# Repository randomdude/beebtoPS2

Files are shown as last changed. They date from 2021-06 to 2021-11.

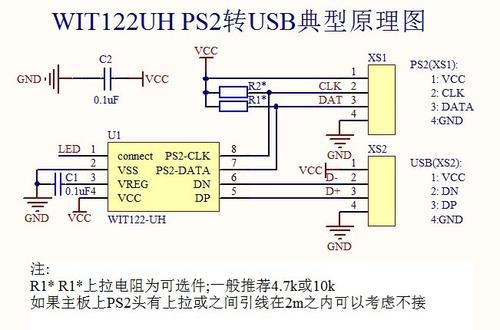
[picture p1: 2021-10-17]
dox/wit122uh.jpg

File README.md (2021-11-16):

Here's a project to enable you to use a modern (ish) PS/2 keyboard on your BBC Micro.

It is built around a Xilinx XC95144XL CPLD. Originally it was in a XC9572, which I love because they are 5v tolerant and also available in PLCC package. However, the design outgrew that chip, and so the TQFP XC95144XL is now required.

The board itself is pretty simple. There's a comparator and a couple octal buffers to sequence power, since otherwise the IO lines may go higher than vcc during power-up, by enough that the CPLD can be damaged. Then there's just the PS/2 socket for your keyboard, 8 debug LEDs, and some DIP switches (which map to the BBC micro's configuration bits). 

Please let me know if you build one, or find this interesting!

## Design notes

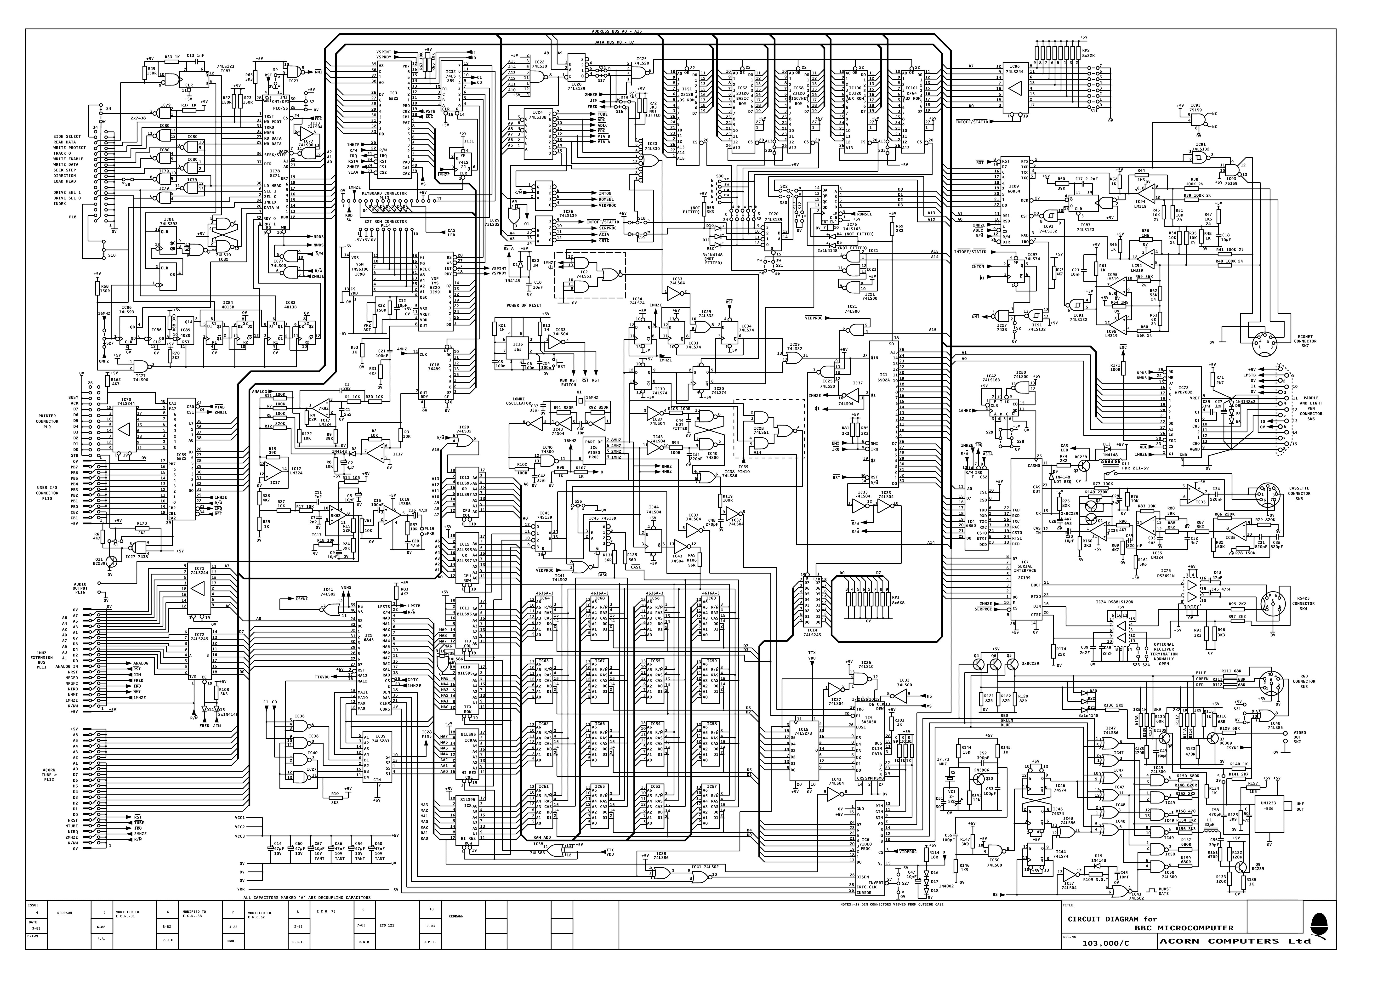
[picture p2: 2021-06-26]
dox/BBC B schematics clean.png

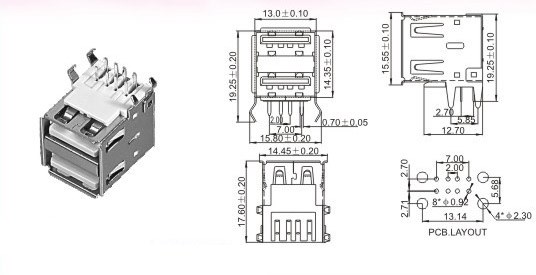
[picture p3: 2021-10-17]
dox/usbsocket.jpg

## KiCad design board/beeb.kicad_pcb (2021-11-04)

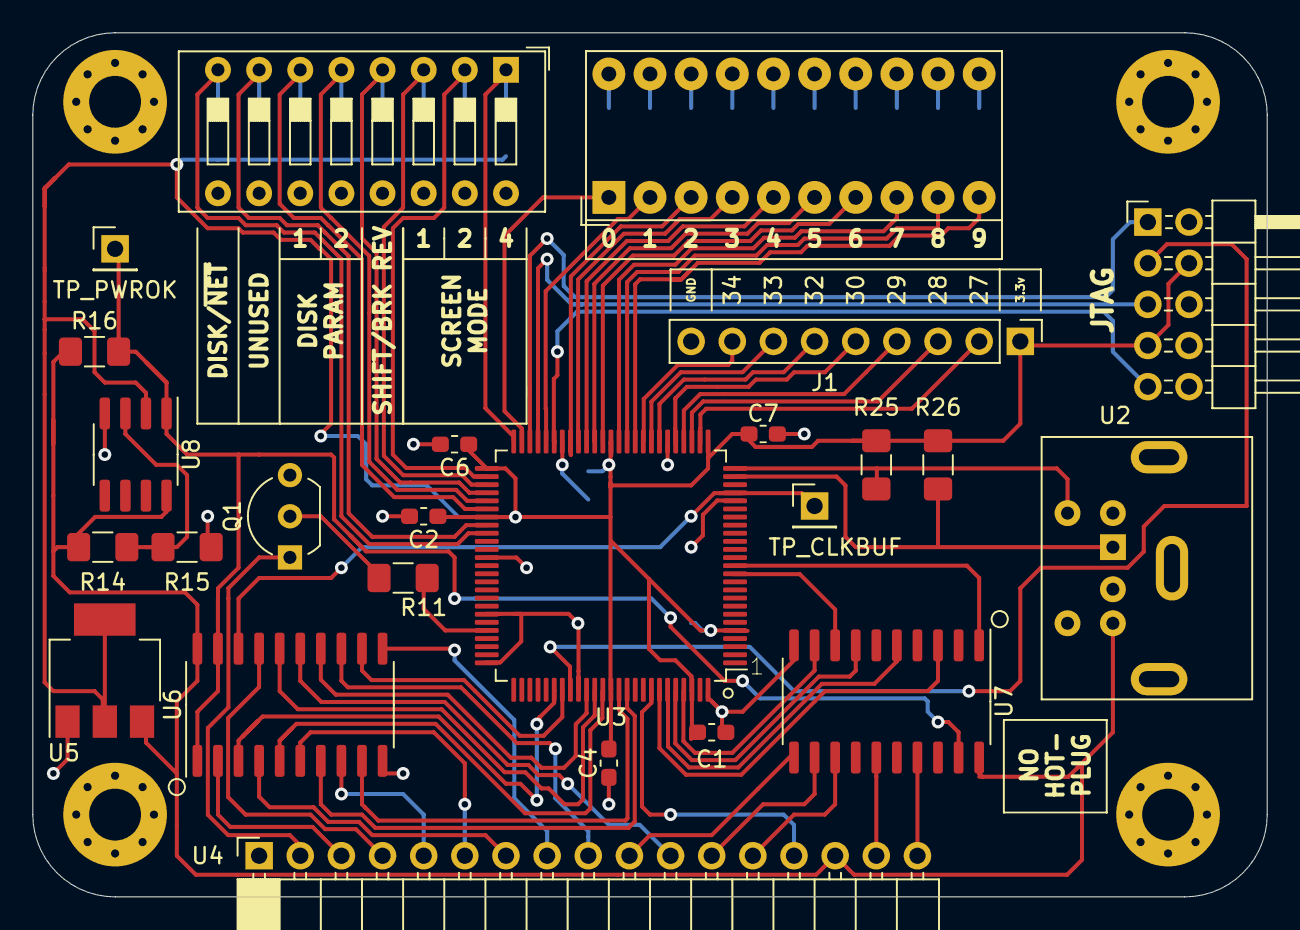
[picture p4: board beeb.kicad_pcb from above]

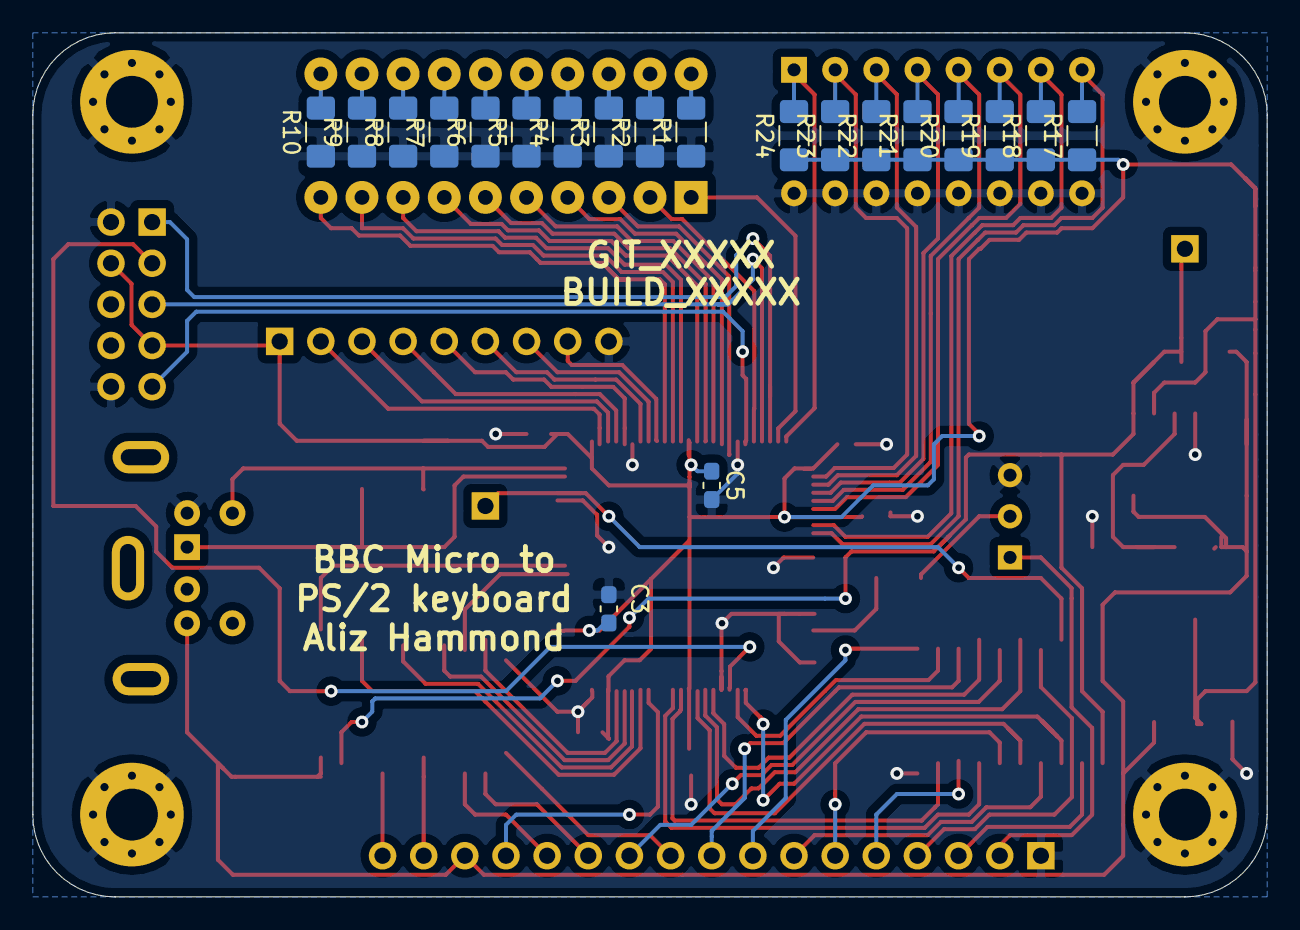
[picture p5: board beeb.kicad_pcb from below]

Board: 2 copper layers, 76.2 x 53.3 mm, 49 parts (20 on the bottom side), 77 nets.

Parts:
BAR1: HDSP-4830_2; HDSP-4830
C1, C2, C3, C4, C5, C6, C7: C; C_0603_1608Metric_Pad1.05x0.95mm_HandSolder
H1, H2, H3, H4: MountingHole_Pad; MountingHole_3.2mm_M3_Pad_Via
J1: Conn_01x09_Male; PinHeader_1x09_P2.54mm_Vertical
J2: AVR-JTAG-10; PinHeader_2x05_P2.54mm_Horizontal
Q1: BC337; TO-92_Inline_Wide
R1, R2, R3, R4, R5, R6, R7, R8, R9, R10, R16, R17, R18, R19, R20, R21, R22, R23, R24, R25, R26: 10K; R_1206_3216Metric_Pad1.42x1.75mm_HandSolder
R11: 220; R_1206_3216Metric_Pad1.42x1.75mm_HandSolder
R14, R15: R; R_1206_3216Metric_Pad1.42x1.75mm_HandSolder
SW1: SW_DIP_x08; SW_DIP_SPSTx08_Slide_9.78x22.5mm_W7.62mm_P2.54mm
TP1: TP_PWROK; PinHeader_1x01_P2.54mm_Vertical
TP2: TP_CLKBUF; PinHeader_1x01_P2.54mm_Vertical
U2: ps2; Connector_Mini-DIN_Female_6Pin_2rows
U3: XC95144XL-TQ100; TQFP-100_14x14mm_P0.5mm
U4: beebKB; PinSocket_1x17_P2.54mm_Horizontal
U5: LM1117-3.3; SOT-223-3_TabPin2
U6, U7: 74LS244_Split; beeb_SO-20_5.3x12.6mm_P1.27mm
U8: LM2903; SOP-8_3.76x4.96mm_P1.27mm

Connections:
+3V3: C1.1, C2.1, C3.1, C4.1, C5.1, C6.1, C7.1, J1.1, J2.4, J2.7, R17.1, R18.1, R19.1, R20.1, R21.1, R22.1, R23.1, R24.1, R25.1, R26.1, U3.5, U3.26, U3.38, U3.51, U3.57, U3.88, U3.98, U5.2, U8.2
+5V: R14.1, R16.1, U2.4, U4.15, U5.3, U6.20, U7.20, U8.8
/BEEBCLK: U4.3, U6.2
/BEEBCLK_BUF: TP2.1, U3.22, U6.18
/CA2: U3.93, U4.14
/CB: U4.4, U6.17
/CB_BUF: U3.81, U6.3
/COL0: U4.5, U6.8
/COL0_BUF: U3.82, U6.12
/COL1: U4.6, U6.6
/COL1_BUF: U3.85, U6.14
/COL2: U4.7, U6.4
/COL2_BUF: U3.86, U6.16
/LED1: BAR1.1, U3.49
/LED2: BAR1.2, U3.46
/LED3: BAR1.3, U3.43
/LED4: BAR1.4, U3.42
/LED5: BAR1.5, U3.41
/LED6: BAR1.6, U3.40
/LED7: BAR1.7, U3.39
/LED8: BAR1.8, U3.37
/LED9: BAR1.9, U3.36
/LED10: BAR1.10, U3.35
/LED_CAPS_BUF: U3.94, U7.3
/LED_CAS_BUF: U3.96, U7.7
/LED_SHIFT_BUF: U3.95, U7.5
/PS2CLK_A: R25.2, U2.5, U3.25
/PS2DATA_A: R26.2, U2.1, U3.24
/PWROK: R16.2, TP1.1, U6.1, U6.19, U7.19, U8.1
/ROW0: U4.8, U6.11
/ROW0_BUF: U3.89, U6.9
/ROW1: U4.9, U6.13
/ROW1_BUF: U3.90, U6.7
/ROW2: U4.10, U7.11
/ROW2_BUF: U3.97, U7.9
/ROW3: U4.11, U6.15
/ROW3_BUF: U3.87, U6.5
/RST: R11.1, U3.71
/TCK: J2.1, U3.48
/TDI: J2.9, U3.45
/TDO: J2.3, U3.83
/TMS: J2.5, U3.47
/W: U4.12, U7.12
/W_BUF: U3.12, U7.8
/W_EN: U3.13, U7.1
GND: C1.2, C2.2, C3.2, C4.2, C5.2, C6.2, C7.2, H1.1, H2.1, H3.1, H4.1, J1.9, J2.2, J2.10, Q1.3, R1.1, R2.1, R3.1, R4.1, R5.1, R6.1, R7.1, R8.1, R9.1, R10.1, R15.2, SW1.9, SW1.10, SW1.11, SW1.12, SW1.13, SW1.14, SW1.15, SW1.16, U2.3, U3.21, U3.31, U3.44, U3.62, U3.69, U3.75, U3.84, U3.100, U4.1, U5.1, U6.10, U7.10, U8.4
unnamed: BAR1.11, R10.2
unnamed: BAR1.12, R9.2
unnamed: BAR1.13, R8.2
unnamed: BAR1.14, R7.2
unnamed: BAR1.15, R6.2
unnamed: BAR1.16, R5.2
unnamed: BAR1.17, R4.2
unnamed: BAR1.18, R3.2
unnamed: BAR1.19, R2.2
unnamed: BAR1.20, R1.2
unnamed: J1.2, U3.27
unnamed: J1.3, U3.28
unnamed: J1.4, U3.29
unnamed: J1.5, U3.30
unnamed: J1.6, U3.32
unnamed: J1.7, U3.33
unnamed: J1.8, U3.34
unnamed: Q1.1, U4.2
unnamed: Q1.2, R11.2
unnamed: R14.2, R15.1, U8.3
unnamed: R17.2, SW1.8, U3.59
unnamed: R18.2, SW1.7, U3.58
unnamed: R19.2, SW1.6, U3.56
unnamed: R20.2, SW1.5, U3.55
unnamed: R21.2, SW1.4, U3.54
unnamed: R22.2, SW1.3, U3.53
unnamed: R23.2, SW1.2, U3.52
unnamed: R24.2, SW1.1, U3.50
unnamed: U4.13, U7.13
unnamed: U4.16, U7.15
unnamed: U4.17, U7.17

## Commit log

2021-06-27 look for PCB in board/ dir
2021-06-27 Widen clearance around jtag vias
    [beeb.kicad_pcb]
2021-06-27 remove spur trace
    [beeb.kicad_pcb]
2021-07-22 Add ps/2 socket footprint from github. Add USB socket via WIT122 IC.
    [beeb.kicad_pcb, beeb.sch]
2021-07-22 Change USB socket footprint, impedence match usb p/n and ps2 clk/data
    [beeb.kicad_pcb, beeb.sch]
2021-08-10 tweak hole placement
    [beeb.kicad_pcb]
2021-08-23 connect CPLD vio to 3.3v, change 3.3v reg to lm1117t
    [beeb.kicad_pcb, beeb.sch]
2021-08-23 fix unconnected pad
    [beeb.kicad_pcb]
2021-08-25 Connect jtag connector to 3v3
    [beeb.kicad_pcb, beeb.sch]
2021-08-25 Update silkscreen
    [beeb.kicad_pcb]
2021-09-01 fix some tests, change debug LEDs
2021-10-17 Make it work
    [beeb.kicad_pcb, beeb.sch]
2021-10-17 add dual usb socket diagram
2021-10-17 Move silk, correct beebkb symbol
    [beeb.kicad_pcb, beeb.sch]
2021-10-21 Remove USB connector, move JTAG connector, mess about
    [beeb.kicad_pcb, beeb.sch]
2021-10-22 Add reset line, remov vref pot
    [beeb.kicad_pcb, beeb.sch]
2021-11-03 Connect U8 to power/gnd, change U6 and U7 footprint, add TP_CLKBUF, tidy
    [beeb.kicad_pcb, beeb.sch]
2021-11-04 Tidy schematic a little
    [beeb.kicad_pcb, beeb.sch]
2021-11-04 correct inverted dip sw
    [beeb.kicad_pcb, beeb.sch]
